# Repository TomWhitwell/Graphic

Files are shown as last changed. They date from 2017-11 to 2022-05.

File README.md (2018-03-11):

# Graphic

A simple, compact and high quality seven band graphic equaliser for Eurorack. Inspired by the Boss GE-7 pedal, but with pristine low-noise circuitry and a much broader frequency range. Simple (if repetitive) SMD soldering with human-sized components. 

Bolder DIYers can easily modify the frequency bands by swapping resistors and capacitors. 

The 5 x N5532 chips draw 7.8ma each (which is in line with the datasheet) = 39ma. They do get quite warm, which seems not abnormal for this chip - you can feel the warmth on the panel! 

With 2k resistors, the 7xLEDs draw  about 38ma making a total of 77ma, which seems quite high compared with simpler circuits using a couple of low-draw Op Amps like the TL072. This circuit will probably work fine with TL072, which would use 14ma (making a total of 52ma) but risks being more noisy. (Now I understand why battery-powered stompboxes like the GE-7 are designed in a way that leaves them rather noisy... )

The PCB panel includes two holes for M2 x 6mm bolts (48SM006) to make the constuction stronger. Place a 3mm spacer between the panel and the slider. 

This m2 x 2.9mm spacer should work: 710-9774015243R, and thisthis M2.5 x 3mm 761-M0502-25-AL should also work OK. 

## Notes on assembling the boards with SMD pre-populated: 
1. There are only two types of parts to attach: Sliders and Sockets.  
1. First, position the sliders. They have 4 pins on one end, 2 pins on the other, so it's impossible to get them the wrong way around. Carefully straighten the pins a little if they don't fit into the holes. I find it easier to insert the 2 pin side first, then slide the 4 pins into place. 
1. Position all the sliders before starting to solder, making sure they're completely even and flat. 
1. Soldering the sliders is simple, but this is a dense board, and you are soldering on the same side as the small surface mount components. In a few places - for example close to the unpopulated C32 - it is very tight. Be careful not to connect the empty solder pads of C32 to the pins, as this will cause strangeness.
1. When soldering the sliders, all the pins should the same length; if you see some that are a bit short, check they're properly pushed through. Otherwise the solders won't be flat and even. 
1. Check all the slider joints - if you miss a connection you can get weird intermittent issues that are hard to debug. 
1. Once the sliders are done, put the sockets in place, then put the front panel on. Ensure the Input socket is at the bottom and the output socket is at the top. Losely tighten the bolts and make sure it all looks right before soldering the three points on the back of each socket.

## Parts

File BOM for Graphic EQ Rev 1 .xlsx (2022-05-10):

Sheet: PCB Assembly BOM
Manufacturer | Manufacturer Part Number | Designator | Qty | Description | Case | SMD ,BGA,LCC,OR TH | Top/Bottom | points | Total points | Comment
Murata | GRM31CR61C226KE15L | C1, C2 | 2 | 22u C-USC1206 | C1206 | SMD | TOP | 1 | Murata | GRM31CR61C226KE15L | C1, C2 | 2 | 22uF,16V,10%,X5R,1206 | 1206 | SMD | Top | 2 | 4
Murata | GRM219R71H333KA01D | C10, C16, C17 | 3 | 33nf CAPACITOR-0805 | C0805 | SMD | TOP | 1 | Murata | GRM219R71H333KA01D | C10, C16, C17 | 3 | 33nF,50V,10%,X7R,0805 | 0805 | SMD | Top | 2 | 6
Murata | GCM21BR72A104KA37L | C11, C14, C4, C6, C9, C12, C13, C28, C29, C30 | 10 | 100n CAPACITOR-0805 | C0805 | SMD | TOP | 1 | Murata | GCM21BR72A104KA37L | C11, C14, C4, C6, C9, C12, C13, C28, C29, C30 | 10 | 100nF,100V,10%,X7R,0805 | 0805 | SMD | Top | 2 | 20
Murata | GRM21BR71H473KA01L | C15 | 1 | 47n CAPACITOR-0805 | C0805 | SMD | TOP | 1 | Murata | GRM21BR71H473KA01L | C15 | 1 | 47nF,50V,10%,X7R,0805 | 0805 | SMD | Top | 2 | 2
Murata | GRM216R71H103KA01D | C18, C22 | 2 | 10n CAPACITOR-0805 | C0805 | SMD | TOP | 1 | Murata | GRM216R71H103KA01D | C18, C22 | 2 | 10nF,50V,10%,X7R,0805 | 0805 | SMD | Top | 2 | 4
Murata | GRM216R71H222KA01D | C19, C24 | 2 | 2.2n CAPACITOR-0805 | C0805 | SMD | TOP | 1 | Murata | GRM216R71H222KA01D | C19, C24 | 2 | 2.2nF,50V,10%,X7R,0805 | 0805 | SMD | Top | 2 | 4
Murata | GRM216R71H472KA01D (https://octopart.com/grm216r71h472ka01d-murata-5464355?r=sp&s=oBoQLLm5T36gKi5BQS4lZA) | C20, C23 | 2 | 4.7n CAPACITOR-0805 | C0805 | SMD | TOP | 1 | Murata | GRM216R71H472KA01D | C20, C23 | 2 | 4.7nF,50V,10%,X7R,0805 | 0805 | SMD | Top | 2 | 4
Murata | GRM216R71H223KA01D | C21 | 1 | 22nf CAPACITOR-0805 | C0805 | SMD | TOP | 1 | Murata | GRM216R71H223KA01D | C21 | 1 | 22nF,50V,10%,X7R,0805 | 0805 | SMD | Top | 2 | 2
Murata | GRM216R71H102KA01D | C25 | 1 | 1n CAPACITOR-0805 | C0805 | SMD | TOP | 1 | Murata | GRM216R71H102KA01D | C25 | 1 | 1nF,50V,10%,X7R,0805 | 0805 | SMD | Top | 2 | 2
Murata | GRM216R71H471KA01D | C26 | 1 | 470pf CAPACITOR-0805 | C0805 | SMD | TOP | 1 | Murata | GRM216R71H471KA01D | C26 | 1 | 470pF,50V,10%,X7R,0805 | 0805 | SMD | Top | 2 | 2
Murata | GRM216R71H221KA01D | C27 | 1 | 220pf CAPACITOR-0805 | C0805 | SMD | TOP | 1 | Murata | GRM216R71H221KA01D | C27 | 1 | 220pF,50V,10%,X7R,0805 | 0805 | SMD | Top | 2 | 2
Murata | GRM21BR71H474KA88L | C3, C5, C8 | 3 | 470nf CAPACITOR-0805 | C0805 | SMD | TOP | 1 | Murata | GRM21BR71H474KA88L | C3, C5, C8 | 3 | 470nF,50V,10%,X7R,0805 | 0805 | SMD | Top | 2 | 6
 |  | C31, C32, C33, C34, C35, C36, C37, C38 | 8 | DO NOT POPULATE | C0805 | SMD | TOP | 1
Murata | GRM21BR71C334KA01L (https://octopart.com/grm21br71c334ka01l-murata-3984619?r=sp&s=5fhOUoJHTm6STkMSUzncvA) | C7 | 1 | 330nf CAPACITOR-0805 | C0805 | SMD | TOP | 1 | Murata | GRM21BR71C334KA01L | C7 | 1 | 330nF,16V,10%,X7R,0805 | 0805 | SMD | Top | 2 | 2
Diodes Inc | 621-1N5819HW-F | D3, D4 | 2 | 5819 DIODE-SOD123 | SOD123 | SMD | TOP | 0 | Diodes Incorporated | 1N5819HW-7-F | D3, D4 | 2 | 40V,1A,SOD-123 | SOD-123 | SMD | Top | 2 | 4
Texas Instruments | NE5532DR | IC1, IC2, IC3, IC4, IC5 | 5 | NE5532D NE5532D | SO08 | SMD | TOP | 1 | Texas Instruments | NE5532DR | IC1, IC2, IC3, IC4, IC5 | 5 | NE5532DR,SOIC-8 | SOIC-8 | SMD | Top | 8 | 40
Molex | 15-91-2100 | JP2 | 1 | M05X2SHD_SMD M05X2SHD_SMD | 2X5-SHROUDED_SMD | SMD | TOP | 1 | Molex | 15-91-2100 | JP2 | 1 | 2*5pin, pitches2.54mm,180° | pitches2.54mm | SMD | Top | 10 | 10
Yageo | RC0805FR-072K7L | R1, R2 | 2 | 2.7k RESISTOR-0805 | C0805 | SMD | TOP | 1 | Yageo | RC0805FR-072K7L | R1, R2 | 2 | 2.7K,1%,1/8W,0805 | 0805 | SMD | Top | 2 | 4
Yageo | RC0805FR-0782KL | R11 | 1 | 82k RESISTOR-0805 | C0805 | SMD | TOP | 1 | Yageo | RC0805FR-0782KL | R11 | 1 | 82K,1%,1/8W,0805 | 0805 | SMD | Top | 2 | 2
Yageo | RC0805FR-0768KL | R13 | 1 | 68k RESISTOR-0805 | C0805 | SMD | TOP | 1 | Yageo | RC0805FR-0768KL | R13 | 1 | 68K,1%,1/8W,0805 | 0805 | SMD | Top | 2 | 2
Yageo | RC0805FR-0762KL | R15 | 1 | 62k RESISTOR-0805 | C0805 | SMD | TOP | 1 | Yageo | RC0805FR-0762KL | R15 | 1 | 62K,1%,1/8W,0805 | 0805 | SMD | Top | 2 | 2
Yageo | RC0805FR-0751KL | R17 | 1 | 51k RESISTOR-0805 | C0805 | SMD | TOP | 1 | Yageo | RC0805FR-0751KL | R17 | 1 | 51K,1%,1/8W,0805 | 0805 | SMD | Top | 2 | 2
Yageo | RC0805FR-072KL | R18, R19, R20, R21, R22, R23, R24 | 7 | 2k RESISTOR-0805 | C0805 | SMD | TOP | 1 | Yageo | RC0805FR-072KL | R18, R19, R20, R21, R22, R23, R24 | 7 | 2K,1%,1/8W,0805 | 0805 | SMD | Top | 2 | 14
Yageo | RC0805FR-0710KL | R25, R26 | 2 | 10k RESISTOR-0805 | C0805 | SMD | TOP | 1 | Yageo | RC0805FR-0710KL | R25, R26 | 2 | 10K,1%,1/8W,0805 | 0805 | SMD | Top | 2 | 4
Yageo | RC0805FR-07470RL | R3 | 1 | 470R RESISTOR-0805 | C0805 | SMD | TOP | 1 | Yageo | RC0805FR-07470RL | R3 | 1 | 470R,1%,1/8W,0805 | 0805 | SMD | Top | 2 | 2
Yageo | RC0805FR-071K8L | R4, R6, R8, R10, R12, R14, R16 | 7 | 1.8k RESISTOR-0805 | C0805 | SMD | TOP | 0 | Yageo | RC0805FR-071K8L | R4, R6, R8, R10, R12, R14, R16 | 7 | 1.8K,1%,1/8W,0805 | 0805 | SMD | Top | 2 | 14
Yageo | RC0805FR-07130KL | R5 | 1 | 130k RESISTOR-0805 | C0805 | SMD | TOP | 0 | Yageo | RC0805FR-07130KL | R5 | 1 | 130K,1%,1/8W,0805 | 0805 | SMD | Top | 2 | 2
Yageo | RC0805FR-07110KL | R7 | 1 | 110k RESISTOR-0805 | C0805 | SMD | TOP | 0 | Yageo | RC0805FR-07110KL | R7 | 1 | 110K,1%,1/8W,0805 | 0805 | SMD | Top | 2 | 2
Yageo | RC0805FR-0791KL | R9 | 1 | 91k RESISTOR-0805 | C0805 | SMD | TOP | 0 | Yageo | RC0805FR-0791KL | R9 | 1 | 91K,1%,1/8W,0805 | 0805 | SMD | Top | 2 | 2

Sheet: RAW Eagle BOM
Qty | Value | Device | Package | Parts | Description
7 |  | ALPHA_20MM_ILLUM_FADER | ALPHA_ILL_FADER_20MM_REV2 | 1KHZ, 2.5KHZ, 7.7KHZ, 16KHZ, 63HZ, 160HZ, 410HZ | 20mm Alpha Illuminated Fader
2 | 22u | C-USC1206 | C1206 | C1, C2 | CAPACITOR, American symbol
1 | 33nf | CAPACITOR-0805 | C0805 | C10 | Capacitors
2 | 100n | CAPACITOR-0805 | C0805 | C11, C14 | Capacitors
1 | 47n | CAPACITOR-0805 | C0805 | C15 | Capacitors
2 | 33n | CAPACITOR-0805 | C0805 | C16, C17 | Capacitors
1 | 10n | CAPACITOR-0805 | C0805 | C18 | Capacitors
2 | 2.2n | CAPACITOR-0805 | C0805 | C19, C24 | Capacitors
2 | 4.7n | CAPACITOR-0805 | C0805 | C20, C23 | Capacitors
1 | 22nf | CAPACITOR-0805 | C0805 | C21 | Capacitors
1 | 10nf | CAPACITOR-0805 | C0805 | C22 | Capacitors
1 | 1n | CAPACITOR-0805 | C0805 | C25 | Capacitors
1 | 470pf | CAPACITOR-0805 | C0805 | C26 | Capacitors
1 | 220pf | CAPACITOR-0805 | C0805 | C27 | Capacitors
3 | 470nf | CAPACITOR-0805 | C0805 | C3, C5, C8 | Capacitors
8 | NP | CAPACITOR-0805 | C0805 | C31, C32, C33, C34, C35, C36, C37, C38 | Capacitors
8 | 100n | RESISTOR-0805 | C0805 | C4, C6, C9, C12, C13, C28, C29, C30 | Resistors
1 | 330nf | CAPACITOR-0805 | C0805 | C7 | Capacitors
2 | 5819 | DIODE-SOD123 | SOD123 | D3, D4 | DIODE
2 | FIDUCIAL1.5X3 | FIDUCIAL1.5X3 | FIDUCIAL-1.5X3 | FID1, FID2 | Fiducial Alignment Points
5 | NE5532D | NE5532D | SO08 | IC1, IC2, IC3, IC4, IC5 | AUDIO AMPLIFIER
2 | THONKICONNNEW | THONKICONNNEW | WQP-PJ301M-12_JACK | INPUT, OUTPUT | 3.5mm socket for Eurorack modular synths
1 | M05X2SHD_SMD | M05X2SHD_SMD | 2X5-SHROUDED_SMD | JP2 | Header 5x2
2 | 2.7k | RESISTOR-0805 | C0805 | R1, R2 | Resistors
1 | 82k | RESISTOR-0805 | C0805 | R11 | Resistors
1 | 68k | RESISTOR-0805 | C0805 | R13 | Resistors
1 | 62k | RESISTOR-0805 | C0805 | R15 | Resistors
1 | 51k | RESISTOR-0805 | C0805 | R17 | Resistors
7 | 2k | RESISTOR-0805 | C0805 | R18, R19, R20, R21, R22, R23, R24 | Resistors
2 | 10k | RESISTOR-0805 | C0805 | R25, R26 | Resistors
1 | 470R | RESISTOR-0805 | C0805 | R3 | Resistors
7 | 1.8k | RESISTOR-0805 | C0805 | R4, R6, R8, R10, R12, R14, R16 | Resistors
1 | 130k | RESISTOR-0805 | C0805 | R5 | Resistors
1 | 110k | RESISTOR-0805 | C0805 | R7 | Resistors
1 | 91k | RESISTOR-0805 | C0805 | R9 | Resistors

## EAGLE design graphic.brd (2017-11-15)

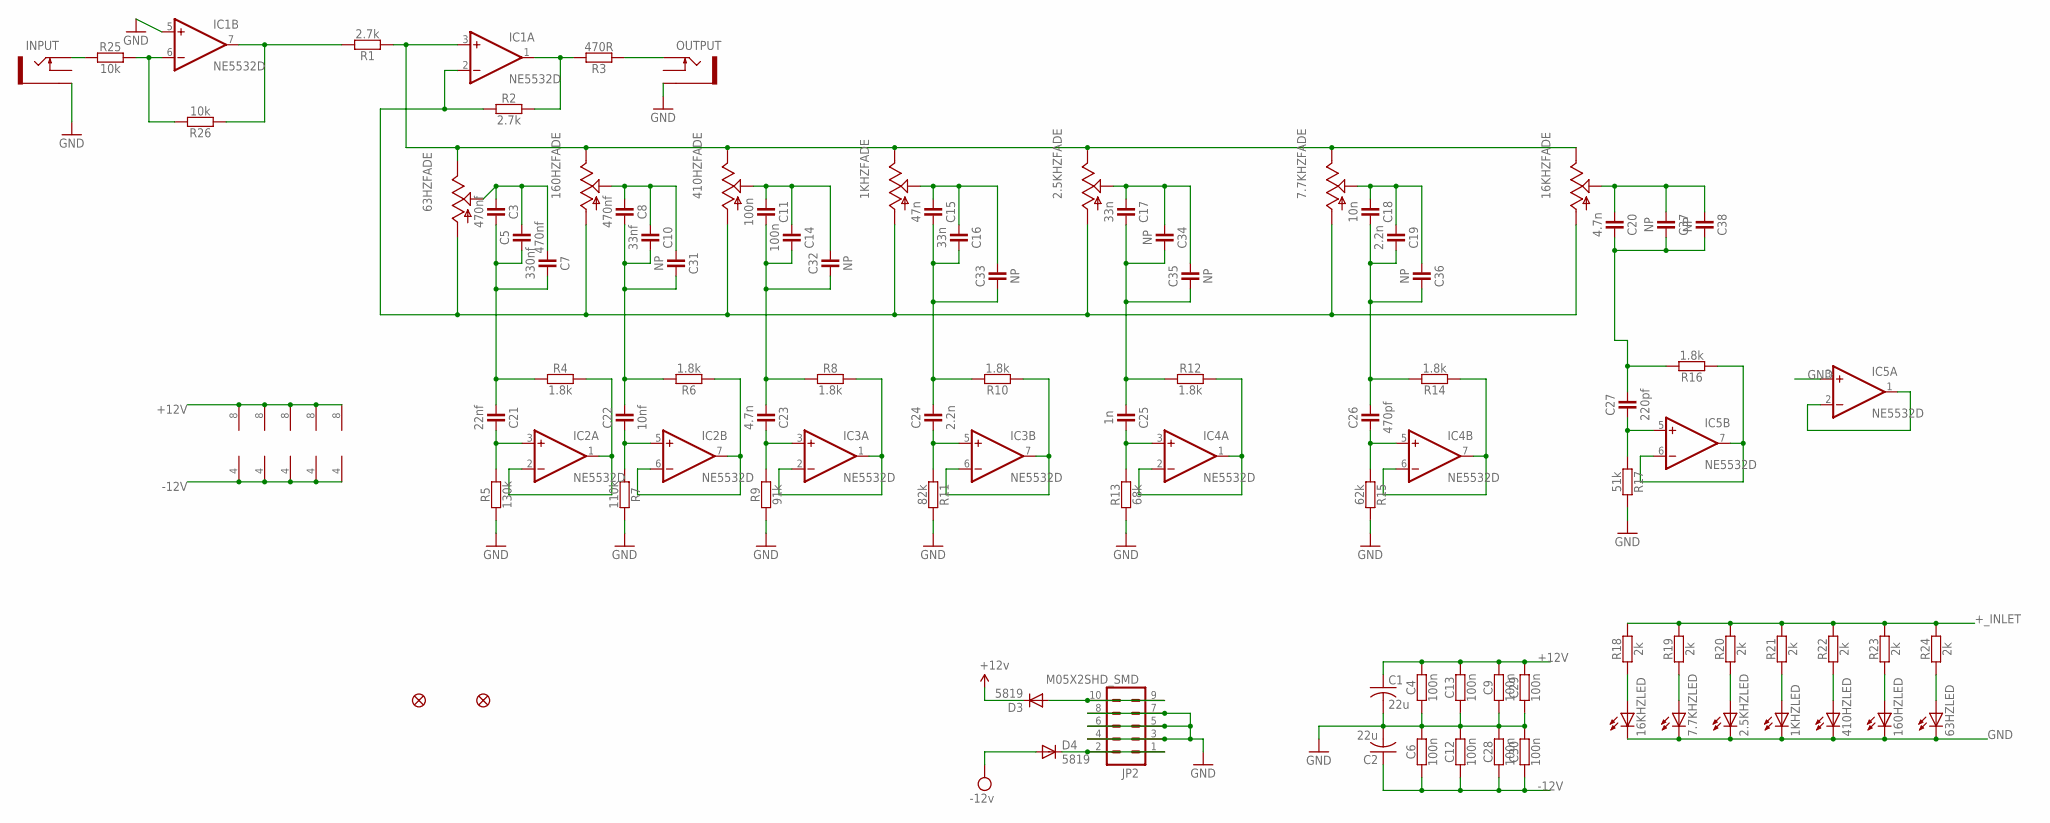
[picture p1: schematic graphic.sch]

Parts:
1KHZ, 2.5KHZ, 7.7KHZ, 16KHZ, 63HZ, 160HZ, 410HZ: ALPHA_20MM_ILLUM_FADER; ALPHA_ILL_FADER_20MM_REV2
C1, C2: 22u; C1206
C3, C5, C8: 470nf; C0805
C4, C6, C9, C11, C12, C13, C14, C28, C29, C30: 100n; C0805
C7: 330nf; C0805
C10: 33nf; C0805
C15: 47n; C0805
C16, C17: 33n; C0805
C18: 10n; C0805
C19, C24: 2.2n; C0805
C20, C23: 4.7n; C0805
C21: 22nf; C0805
C22: 10nf; C0805
C25: 1n; C0805
C26: 470pf; C0805
C27: 220pf; C0805
C31, C32, C33, C34, C35, C36, C37, C38: NP; C0805
D3, D4: 5819; SOD123
FID1, FID2: FIDUCIAL1.5X3; FIDUCIAL-1.5X3
IC1, IC2, IC3, IC4, IC5: NE5532D; SO08
INPUT: THONKICONNNEW; WQP-PJ301M-12_JACK
JP2: M05X2SHD_SMD; 2X5-SHROUDED_SMD
OUTPUT: THONKICONNNEW; WQP-PJ301M-12_JACK
R1, R2: 2.7k; C0805
R3: 470R; C0805
R4, R6, R8, R10, R12, R14, R16: 1.8k; C0805
R5: 130k; C0805
R7: 110k; C0805
R9: 91k; C0805
R11: 82k; C0805
R13: 68k; C0805
R15: 62k; C0805
R17: 51k; C0805
R18, R19, R20, R21, R22, R23, R24: 2k; C0805
R25, R26: 10k; C0805

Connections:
+12V: C1.1, C4.2, C9.2, C13.2, C29.2, D3.C, IC1.8 (V+), IC2.8 (V+), IC3.8 (V+), IC4.8 (V+), IC5.8 (V+)
+_INLET: D3.A, JP2.9, JP2.10, R18.2, R19.2, R20.2, R21.2, R22.2, R23.2, R24.2
-12V: C2.1, C6.1, C12.1, C28.1, C30.1, D4.A, IC1.4 (V-), IC2.4 (V-), IC3.4 (V-), IC4.4 (V-), IC5.4 (V-)
-_INLET: D4.C, JP2.1, JP2.2
GND: 1KHZ.E (C), 2.5KHZ.E (C), 7.7KHZ.E (C), 16KHZ.E (C), 63HZ.E (C), 160HZ.E (C), 410HZ.E (C), C1.2, C2.2, C4.1, C6.2, C9.1, C12.2, C13.1, C28.2, C29.1, C30.2, IC1.5 (+IN), IC5.3 (+IN), INPUT.P$3_SLEEVE (SLEEVE), JP2.3, JP2.4, JP2.5, JP2.6, JP2.7, JP2.8, OUTPUT.P$3_SLEEVE (SLEEVE), R5.1, R7.2, R9.1, R11.2, R13.1, R15.2, R17.2
unnamed: INPUT.P$1_TIP (TIP), R25.1
unnamed: 1KHZ.3 (A), 2.5KHZ.3 (A), 7.7KHZ.3 (A), 16KHZ.3 (A), 63HZ.3 (A), 160HZ.3 (A), 410HZ.3 (A), IC1.2 (-IN), R2.1
unnamed: 410HZ.2 (S), C11.1, C14.1, C32.2
unnamed: IC1.1 (OUT), R2.2, R3.2
unnamed: OUTPUT.P$1_TIP (TIP), R3.1
unnamed: 1KHZ.1 (E), 2.5KHZ.1 (E), 7.7KHZ.1 (E), 16KHZ.1 (E), 63HZ.1 (E), 160HZ.1 (E), 410HZ.1 (E), IC1.3 (+IN), R1.1
unnamed: 63HZ.2 (S), C3.1, C5.2, C7.1
unnamed: IC1.6 (-IN), R25.2, R26.2
unnamed: 16KHZ.B (A), R18.1
unnamed: 2.5KHZ.2 (S), C17.1, C34.1, C35.2
unnamed: 1KHZ.2 (S), C15.1, C16.1, C33.2
unnamed: 7.7KHZ.B (A), R19.1
unnamed: 160HZ.2 (S), C8.1, C10.1, C31.1
unnamed: 2.5KHZ.B (A), R20.1
unnamed: C23.2, IC3.3 (+IN), R9.2
unnamed: C3.2, C5.1, C7.2, C21.1, R4.1
unnamed: C8.2, C10.2, C22.2, C31.2, R6.2
unnamed: 7.7KHZ.2 (S), C18.1, C19.1, C36.1
unnamed: 1KHZ.B (A), R21.1
unnamed: IC3.1 (OUT), IC3.2 (-IN), R8.2
unnamed: IC5.1 (OUT), IC5.2 (-IN)
unnamed: 16KHZ.2 (S), C20.1, C37.1, C38.1
unnamed: C24.1, IC3.5 (+IN), R11.1
unnamed: C21.2, IC2.3 (+IN), R5.2
unnamed: IC2.1 (OUT), IC2.2 (-IN), R4.2
unnamed: IC3.6 (-IN), IC3.7 (OUT), R10.1
unnamed: C22.1, IC2.5 (+IN), R7.1
unnamed: IC2.6 (-IN), IC2.7 (OUT), R6.1
unnamed: C11.2, C14.2, C23.1, C32.1, R8.1
unnamed: C15.2, C16.2, C24.2, C33.1, R10.2
unnamed: C25.2, IC4.3 (+IN), R13.2
unnamed: IC4.1 (OUT), IC4.2 (-IN), R12.2
unnamed: C26.1, IC4.5 (+IN), R15.1
unnamed: IC4.6 (-IN), IC4.7 (OUT), R14.1
unnamed: C17.2, C25.1, C34.2, C35.1, R12.1
unnamed: C18.2, C19.2, C26.2, C36.2, R14.2
unnamed: C27.1, IC5.5 (+IN), R17.1
unnamed: IC5.6 (-IN), IC5.7 (OUT), R16.1
unnamed: C20.2, C27.2, C37.2, C38.2, R16.2
unnamed: 410HZ.B (A), R22.1
unnamed: 160HZ.B (A), R23.1
unnamed: 63HZ.B (A), R24.1
unnamed: IC1.7 (OUT), R1.2, R26.1

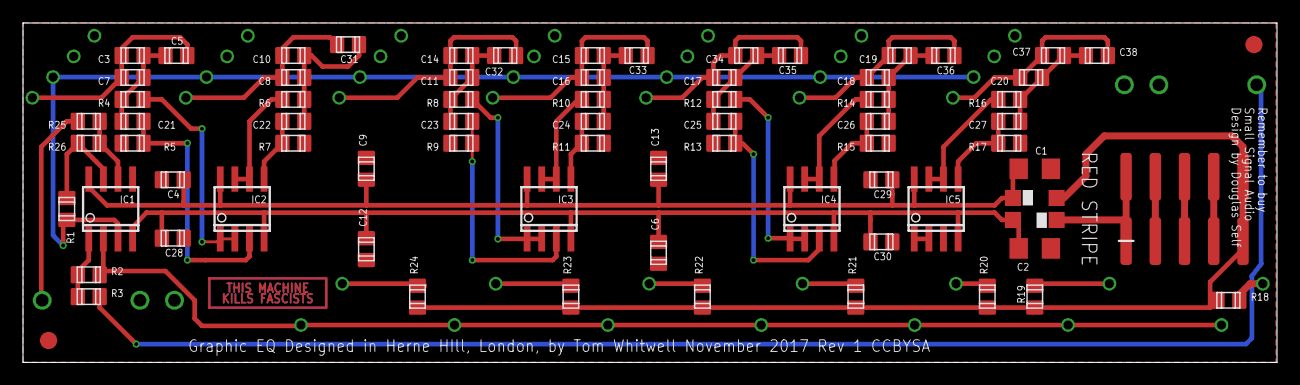
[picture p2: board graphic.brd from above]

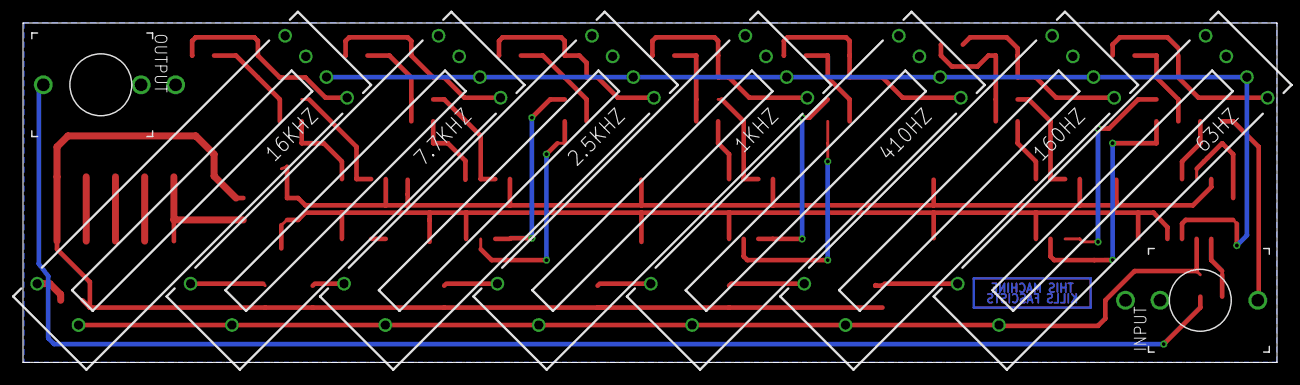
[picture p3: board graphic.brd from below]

Board: 2 copper layers, 109.0 x 29.5 mm, 84 parts (9 on the bottom side), 48 nets.

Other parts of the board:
U$1: TMKF

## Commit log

2017-01-26 Initial upload
    [graphic.brd, graphic.sch]
2017-01-27 Simple version PCB complete and routed
    [graphic.brd, graphic.sch]
2017-01-28 Creating experimental stereo output versions
    [graphic_stereo.brd, graphic_stereo.sch, graphic_stereo_2.brd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]
2017-01-30 Prototype 1 sent to OSHPark
    [graphic.brd, graphic.sch, graphic_panel.brd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]
2017-02-12 updated 20mm fader outlines - NOT moved yet
    [graphic.brd, graphic.sch]
2017-02-12 move sliders and reverse movement
    [graphic.brd, graphic.sch]
2017-02-16 re route and redesign panel
    [graphic.brd, graphic.sch, graphic_panel.brd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]
2017-03-18 Updated illuminated fader outline
    [graphic.brd, graphic.sch, graphic_panel.brd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]
2017-05-11 rev 3 Panel Gerbers
    [graphic_panel.brd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]
2017-05-29 Increase LED resistors to reduce current draw
    [graphic.brd, graphic.sch]
2017-06-10 Remove non-working stereo experiments
    [graphic_stereo.brd, graphic_stereo.sch, graphic_stereo_2.brd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]
2017-08-30 Add schematic + update
    [graphic.brd]
2017-08-30 Revert "Merge branch 'fix-panel'"
    This reverts commit 24303b16601d2e124062e02205cddf4c546a9bcf, reversing
    changes made to eef96a0ff0da711b8061c4b766c52a963260b08f.
    [graphic_stereo.brd, graphic_stereo.sch, graphic_stereo_2.brd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]
2017-09-26 Tweaks for Rev 1 boards: improve ground plane clearance, move one resistor, move Kills Fascists arwork, small changes to get ground plane to work
    [graphic.brd, graphic.sch, graphic_stereo.brd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]
2017-11-15 Revert "Tweaks for Rev 1 boards: improve ground plane clearance, move one resistor, move Kills Fascists arwork, small changes to get ground plane to work"
    This reverts commit c469b6aed1205b33f2cf1fbab66cd5b8357eaae7.
    [graphic_stereo.brd, graphic_stereo.sch, graphic_stereo_2.brd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]
2017-11-15 Revision 1 board finalised - moved one resistor + added Fiducials
    [graphic.brd, graphic.sch, graphic_panel.brd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]
2022-05-10 Add BOM
    [BOM for Graphic EQ Rev 1 .xlsx]

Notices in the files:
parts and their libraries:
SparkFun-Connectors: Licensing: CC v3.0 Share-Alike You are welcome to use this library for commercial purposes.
